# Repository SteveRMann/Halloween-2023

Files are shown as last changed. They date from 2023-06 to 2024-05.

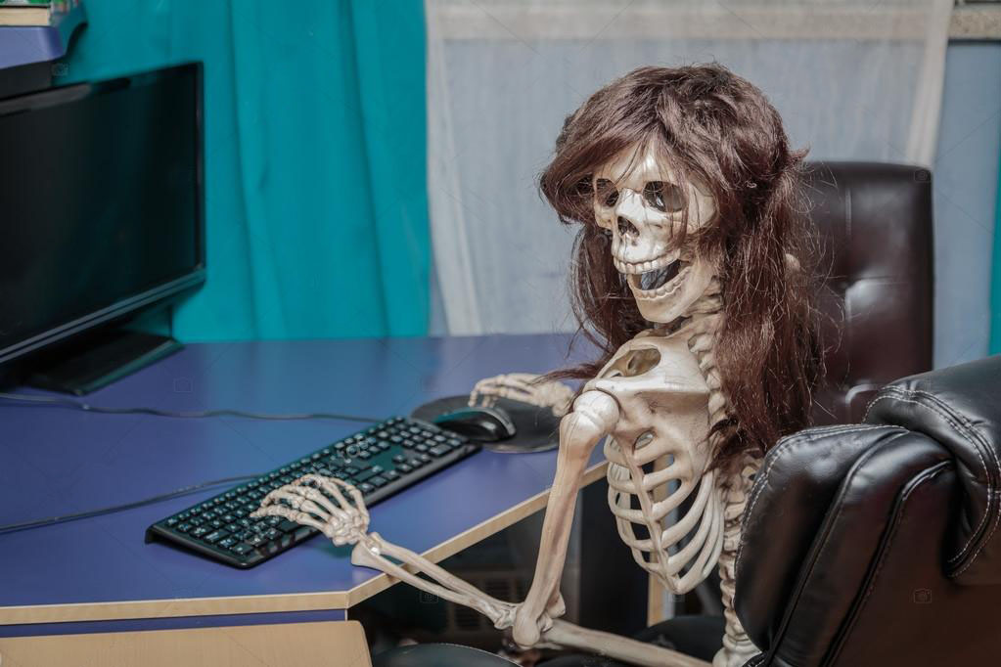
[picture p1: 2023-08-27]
Images/Skeleton Wife.jpg

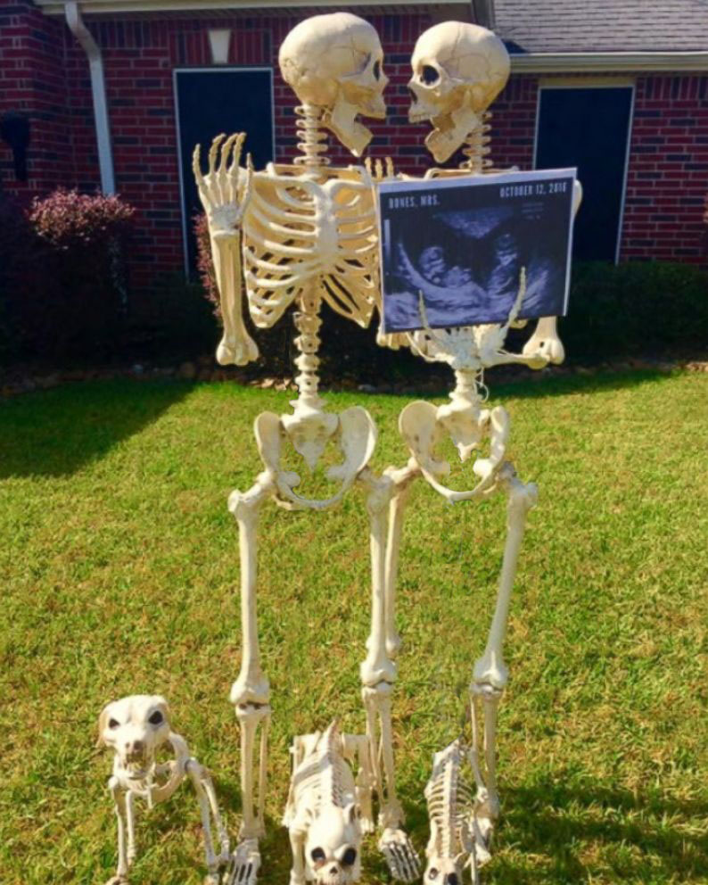
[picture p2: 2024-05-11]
Images/Skeleton Family.jpg

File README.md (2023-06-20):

## PrizeDelivery
This repository contains the files for the Halloween prize delivery mechanism.

The mechanism is a rotisserie motor that rotates on command (a button press).
Once started, the motor continues until a "home" microswitch is closed.
Because the motor is slow, like 20 seconds for 360°, the "home" position is 
just before a drop would occur.

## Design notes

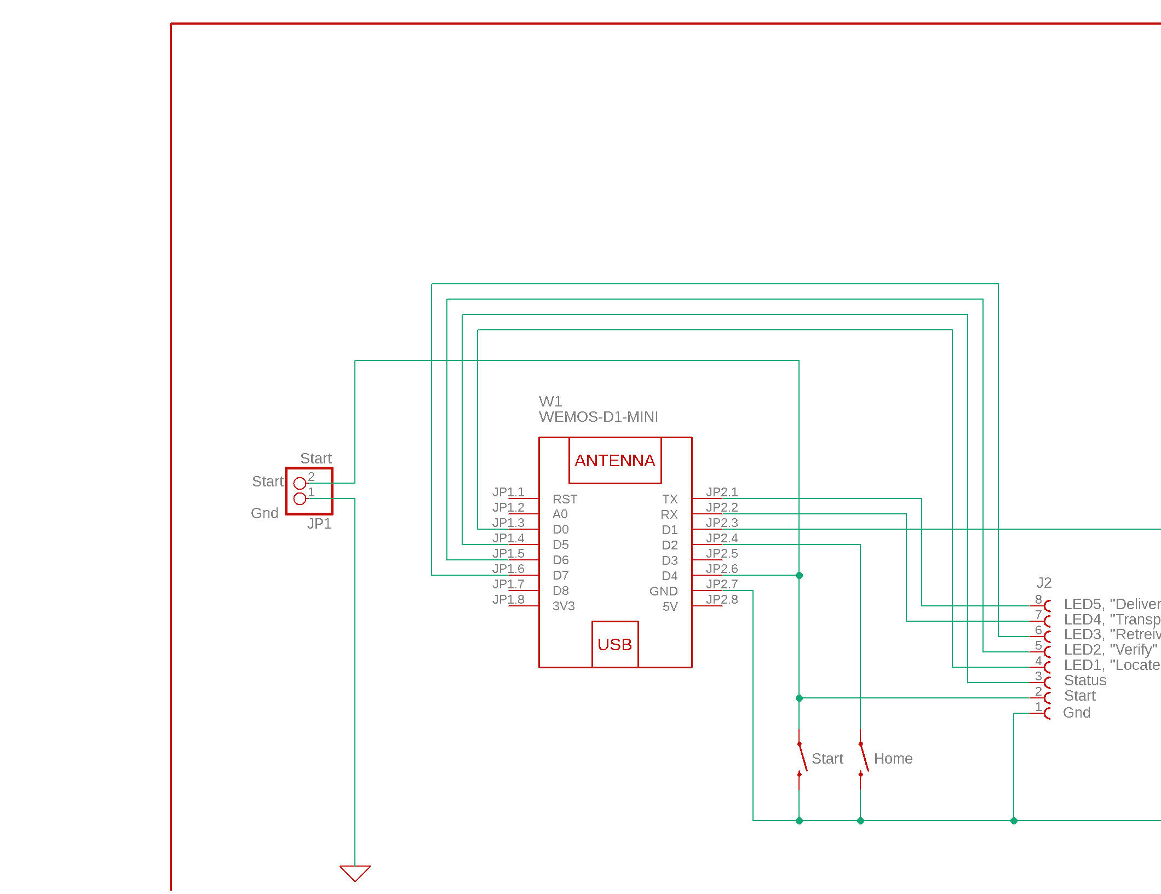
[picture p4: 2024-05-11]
PrizeDelivery/Schematic/Prize Delivery Schematic.jpg

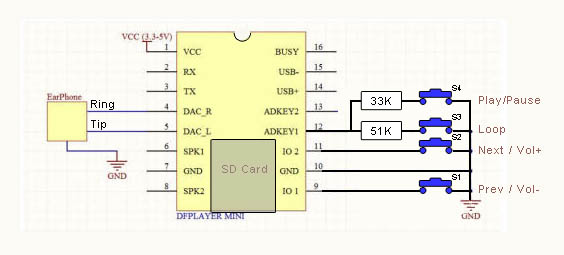
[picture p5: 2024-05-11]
dfPlayer/dfplayer Standalond schematic.jpg

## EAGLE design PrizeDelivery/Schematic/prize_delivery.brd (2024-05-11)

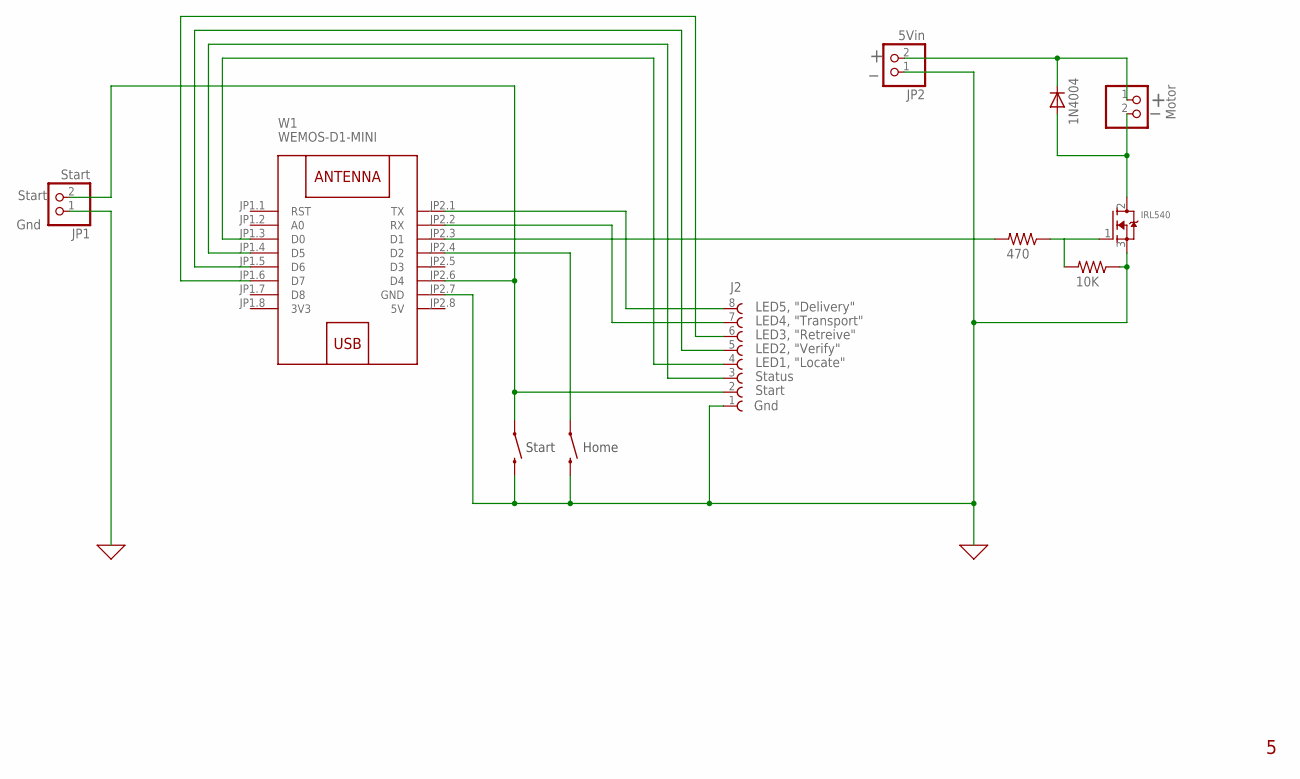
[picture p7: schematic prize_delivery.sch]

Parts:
360°: MOMENTARY-SWITCH-SPST-PTH-6.0MM; TACTILE_SWITCH_PTH_6.0MM
D1: 1N4004; DO41-10
J2: 691136710008
JP1: Start; 1X02
JP2: 5Vin; 1X02
JP3: Motor; 1X02
Q1: IRL540; TO220V
R2: 470; 0207/10
R4: 10K; 0207/10
START: MOMENTARY-SWITCH-SPST-PTH-6.0MM; TACTILE_SWITCH_PTH_6.0MM
W1: WEMOS-D1-MINI

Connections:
0: 360°.3 (2), J2.1, JP1.1, JP2.1, Q1.3 (S), R4.1, START.3 (2), W1.JP2.7 (GND)
3V3: W1.JP1.8 (3V3)
5V: W1.JP2.8 (5V)
unnamed: D1.A, JP3.2, Q1.2 (D)
unnamed: D1.C, JP2.2, JP3.1
unnamed: 360°.1, W1.JP2.4 (D2)
unnamed: R2.2, W1.JP2.3 (D1)
unnamed: J2.2, JP1.2, START.1, W1.JP2.6 (D4)
unnamed: Q1.1 (G), R2.1, R4.2
unnamed: J2.4, W1.JP1.3 (D0)
unnamed: J2.5, W1.JP1.5 (D6)
unnamed: J2.6, W1.JP1.6 (D7)
unnamed: J2.8, W1.JP2.1 (TX)
unnamed: J2.7, W1.JP2.2 (RX)
unnamed: J2.3, W1.JP1.4 (D5)

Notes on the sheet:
Home
Start
Gnd
LED1, "Locate"
LED2, "Verify"
LED3, "Retreive"
LED4, "Transport"
LED5, "Delivery"
Status

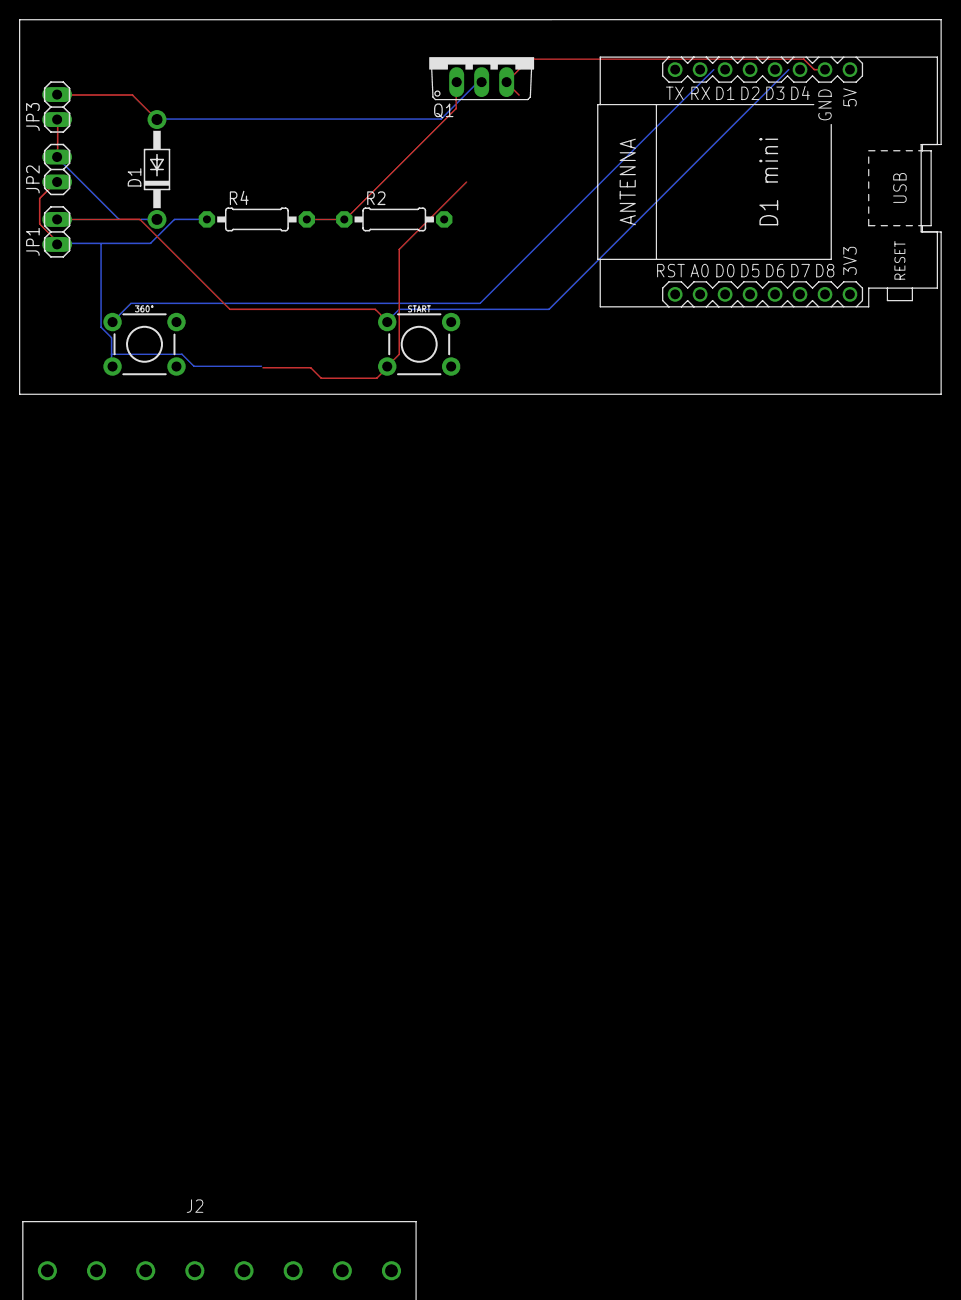
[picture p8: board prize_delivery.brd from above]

Board: 2 copper layers, 93.7 x 38.1 mm, 11 parts (0 on the bottom side), 13 nets.

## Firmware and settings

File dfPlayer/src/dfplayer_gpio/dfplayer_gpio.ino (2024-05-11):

/*
  Control the DFPlayer ADKEY1 pin through a GPIO port.
*/

const int TRACK1_PIN = D5;
const int TRACK2_PIN = D3;
const int PLAY_PAUSE_PIN = D6;
const int PREV_VOLdn_PIN = D1;
const int NEXT_VOLup_PIN = D2;


// ---------- setup ----------
void setup() {
  Serial.begin(115200);
  delay(1);
  Serial.println();
  Serial.println();
  Serial.print(F("dfplayer_gpio.ino"));

  //This makes the GPIO pins float.
  pinMode(D5, INPUT);                   //Track 1
  pinMode(D6, INPUT);                   //Play/Pause
//  pinMode(D7, INPUT);                   //Tx
//  pinMode(D8, INPUT);                   //Rx
  pinMode(D1, INPUT);                   //Prev/Vol-
  pinMode(D2, INPUT);                   //Next/Vol+
  pinMode(D3, INPUT);                   //Track 2
  drawMenu();
}


// ---------- loop ----------
void loop() {
  menu();
}

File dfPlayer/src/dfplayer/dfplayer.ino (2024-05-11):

#define SKETCH "dfplayer"
#define VERSION "1.0"

/*
  Control the DFPlayer ADKEY1 pin through a GPIO port.
*/

const int TRACK1_PIN = D5;
const int TRACK2_PIN = D3;
const int PLAY_PAUSE_PIN = D6;
const int PREV_VOLdn_PIN = D1;
const int NEXT_VOLup_PIN = D2;
//const int TX_PIN = D7;
//const int RX_PIN = D8;


//--------------- WiFi declarations ---------------
// WiFi declarations
#include <ESP8266WiFi.h>        // Not needed if also using the Arduino OTA Library...
#include <Kaywinnet.h>          // WiFi credentials
char macBuffer[24];             // Holds the last three digits of the MAC, in hex.
char hostName[24];              // Holds nodeName + the last three bytes of the MAC address.
char nodeName[] = SKETCH;       // Give this node a name


//--------------- ticker declarations ---------------
//for WiFi status
#include <Ticker.h>
Ticker blueTicker;                       //Ticker object for the WiFi Connecting LED
const int BLUE_LED_PIN = D4;             //D4 is LED_BUILTIN on Wemos D1 Mini


//--------------- MQTT declarations ---------------
#include <ESP8266WiFi.h>        // Connect (and reconnect) an ESP8266 to the a WiFi network.
#include <PubSubClient.h>       // connect to a MQTT broker and publish/subscribe messages in topics.
// Declare an object of class WiFiClient, which allows to establish a connection to a specific IP and port
// Declare an object of class PubSubClient, which receives as input the constructor previously defined with WiFiClient.
// The constructor MUST be unique on the network. (Does it?)
WiFiClient dfplayer;
PubSubClient client(dfplayer);

const char *mqttServer = MQTT_SERVER;         // Local broker defined in Kaywinnet.h
const int mqttPort = 1883;

// Declare strings for the topics. Topics will be created in setup_mqtt().
char statusTopic[20];
char cmndTopic[20];
char rssiTopic[20];

//--------------- OTA declarations ---------------
#include <ArduinoOTA.h>

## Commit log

2023-06-13 New repository
    [lid.brd, lid.sch, timing.xlsx]
2023-06-16 Update schematic
    [lid.brd, lid.sch, prize_delivery.brd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]
2023-06-17 Modified schematic
    [prize_delivery.brd, prize_delivery.sch]
2023-06-17 Update PCB
    [prize_delivery.brd, prize_delivery.sch]
2023-06-20 Switch hardware to D1 Mini Relay Shield
2023-06-29 Reconstruct the schematic and board files
    [prize_delivery.brd, prize_delivery.sch]
2023-08-13 New folders
    [prize_delivery.brd, prize_delivery.sch]
2023-08-27 Added images folder
    [prize_delivery.brd, prize_delivery.sch]
2024-05-11 Not sure
    [DFPlayer-Wemos-ESPHome.sch, DFPlayer-Wemos-GPIO control.sch, prize_delivery.brd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]

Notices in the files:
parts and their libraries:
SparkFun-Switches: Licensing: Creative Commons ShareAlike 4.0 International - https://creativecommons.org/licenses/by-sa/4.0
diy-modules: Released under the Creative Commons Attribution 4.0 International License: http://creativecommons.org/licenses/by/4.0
